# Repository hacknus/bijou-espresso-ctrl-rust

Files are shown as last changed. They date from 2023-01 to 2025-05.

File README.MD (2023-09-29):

### Bijou Espresso Machine Control Software (Rust Code)

This board controls the Bijou Espresso Machine.  
It is based around an STM32F405 microcontroller that reads out 5 PT100 RTDs (2 wire) using 5 MAX31865 ADCs.  
The temperature values are printed out over USB (CDC virtual COM Port) and shown on the SSD1306 OLED display.  
Two heating elements are controlled (SSR40 solid state relays) with PWM signals.  
Additionally a Buzzer and multiple LEDs can be controlled (PWM).  

The software uses freertos-rust (wrapper for rust) and thus requires nightly to compile.  
The embedded-graphics crate is used for the display.

Connect the board using a ST-Link V3 (with TagConnect) to a USB port on the computer. Be sure to power the board with an additional USB-C connector. (ST-Link does not provide power)  
First start the openocd server in a terminal/console window:
```openocd -f interface/stlink-v2-1.cfg -f target/stm32f4x.cfg```   
Flash/Run the code on the hardware using:  
```cargo run --package bijou-espresso-ctrl-rust --bin bijou-espresso-ctrl-rust --target thumbv7em-none-eabihf --release```  

To set up your system, be sure to follow [this guide](https://docs.rust-embedded.org/discovery/f3discovery/03-setup/index.html)!  
Don't forget to install the [ARM GNU toolchain](https://developer.arm.com/downloads/-/arm-gnu-toolchain-downloads).  
Make sure you add did 
```rustup install nightly``` and
```rustup target add thumbv7em-none-eabihf --toolchain nightly``` to add the target to the nightly toolchain.  

TODO:
- implement SPI flash chip in software

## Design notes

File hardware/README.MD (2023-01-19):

## Electronics Hardware of Bijou Espresso Machine 

The main board schematic can be found in `main.sch` and the pcb layout in `main.brd`.  
The AC power measurement board schematic can be found in `AC_board.sch` and the pcb layout in `AC_board.brd`. This is currently not implemented (in software).  
The temperature readout board schematic can be found in `temperature_2.sch` and the pcb layout in `temperature_2.brd`.  
Issues:
- footprint of the mosfets for the LED (Switch) is faulty, needs to be fixed.
- capacitor missing on encoder
- temperature molex connector is the wrong way around (needs to be soldered from the back)
- attention! usb serial resistors are 22 Ohms, not 220 Ohms!!

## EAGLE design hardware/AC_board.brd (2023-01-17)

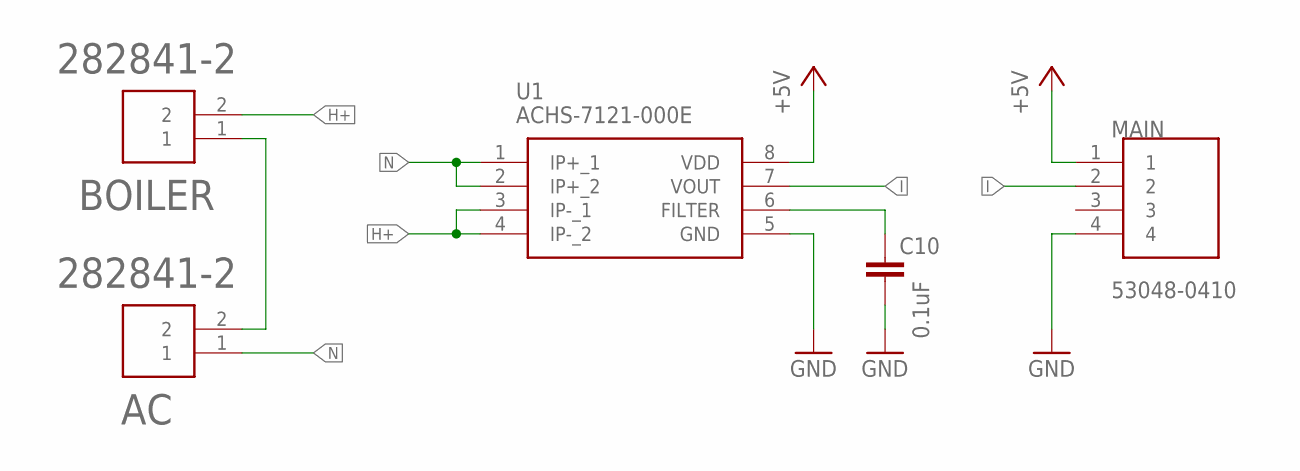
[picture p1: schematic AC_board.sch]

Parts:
AC: 282841-2; TE_282841-2
BOILER: 282841-2; TE_282841-2
C10: 0.1uF; C0603K
MAIN: 53048-0410; 530480410
U1: ACHS-7121-000E; SOIC127P606X204-8N

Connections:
+5V: MAIN.1, U1.8 (VDD)
GND: C10.2, MAIN.4, U1.5 (GND)
H+: BOILER.2, U1.3 (IP-_1), U1.4 (IP-_2)
I: MAIN.2, U1.7 (VOUT)
N: AC.1, U1.1 (IP+_1), U1.2 (IP+_2)
unnamed: C10.1, U1.6 (FILTER)
unnamed: AC.2, BOILER.1

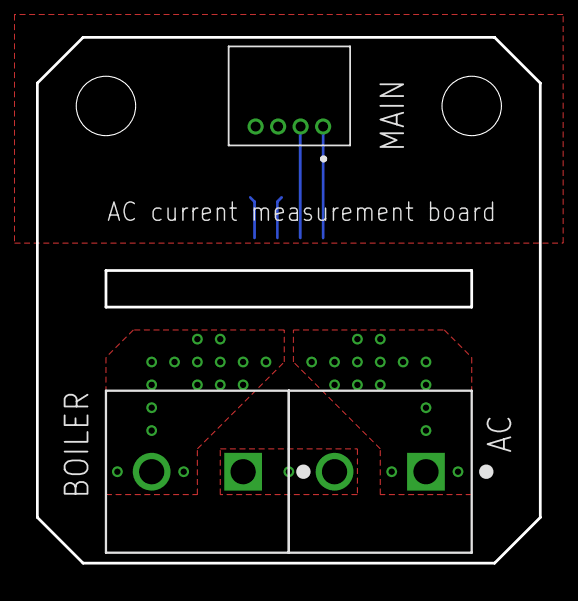
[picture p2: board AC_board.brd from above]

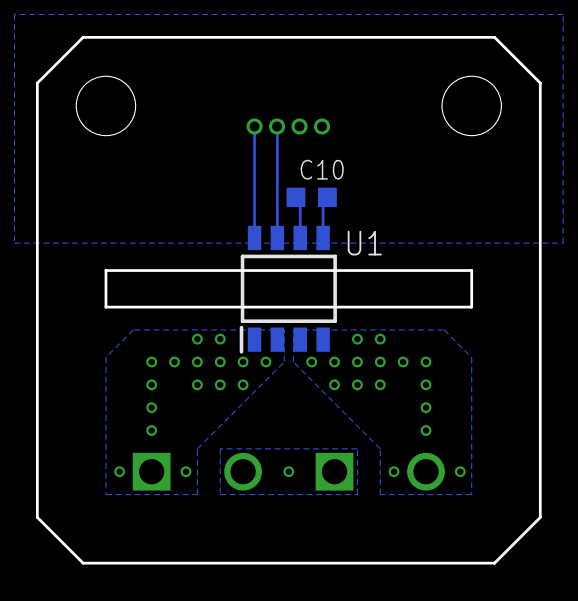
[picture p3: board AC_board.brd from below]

Board: 2 copper layers, 27.9 x 29.2 mm, 5 parts (2 on the bottom side), 7 nets.

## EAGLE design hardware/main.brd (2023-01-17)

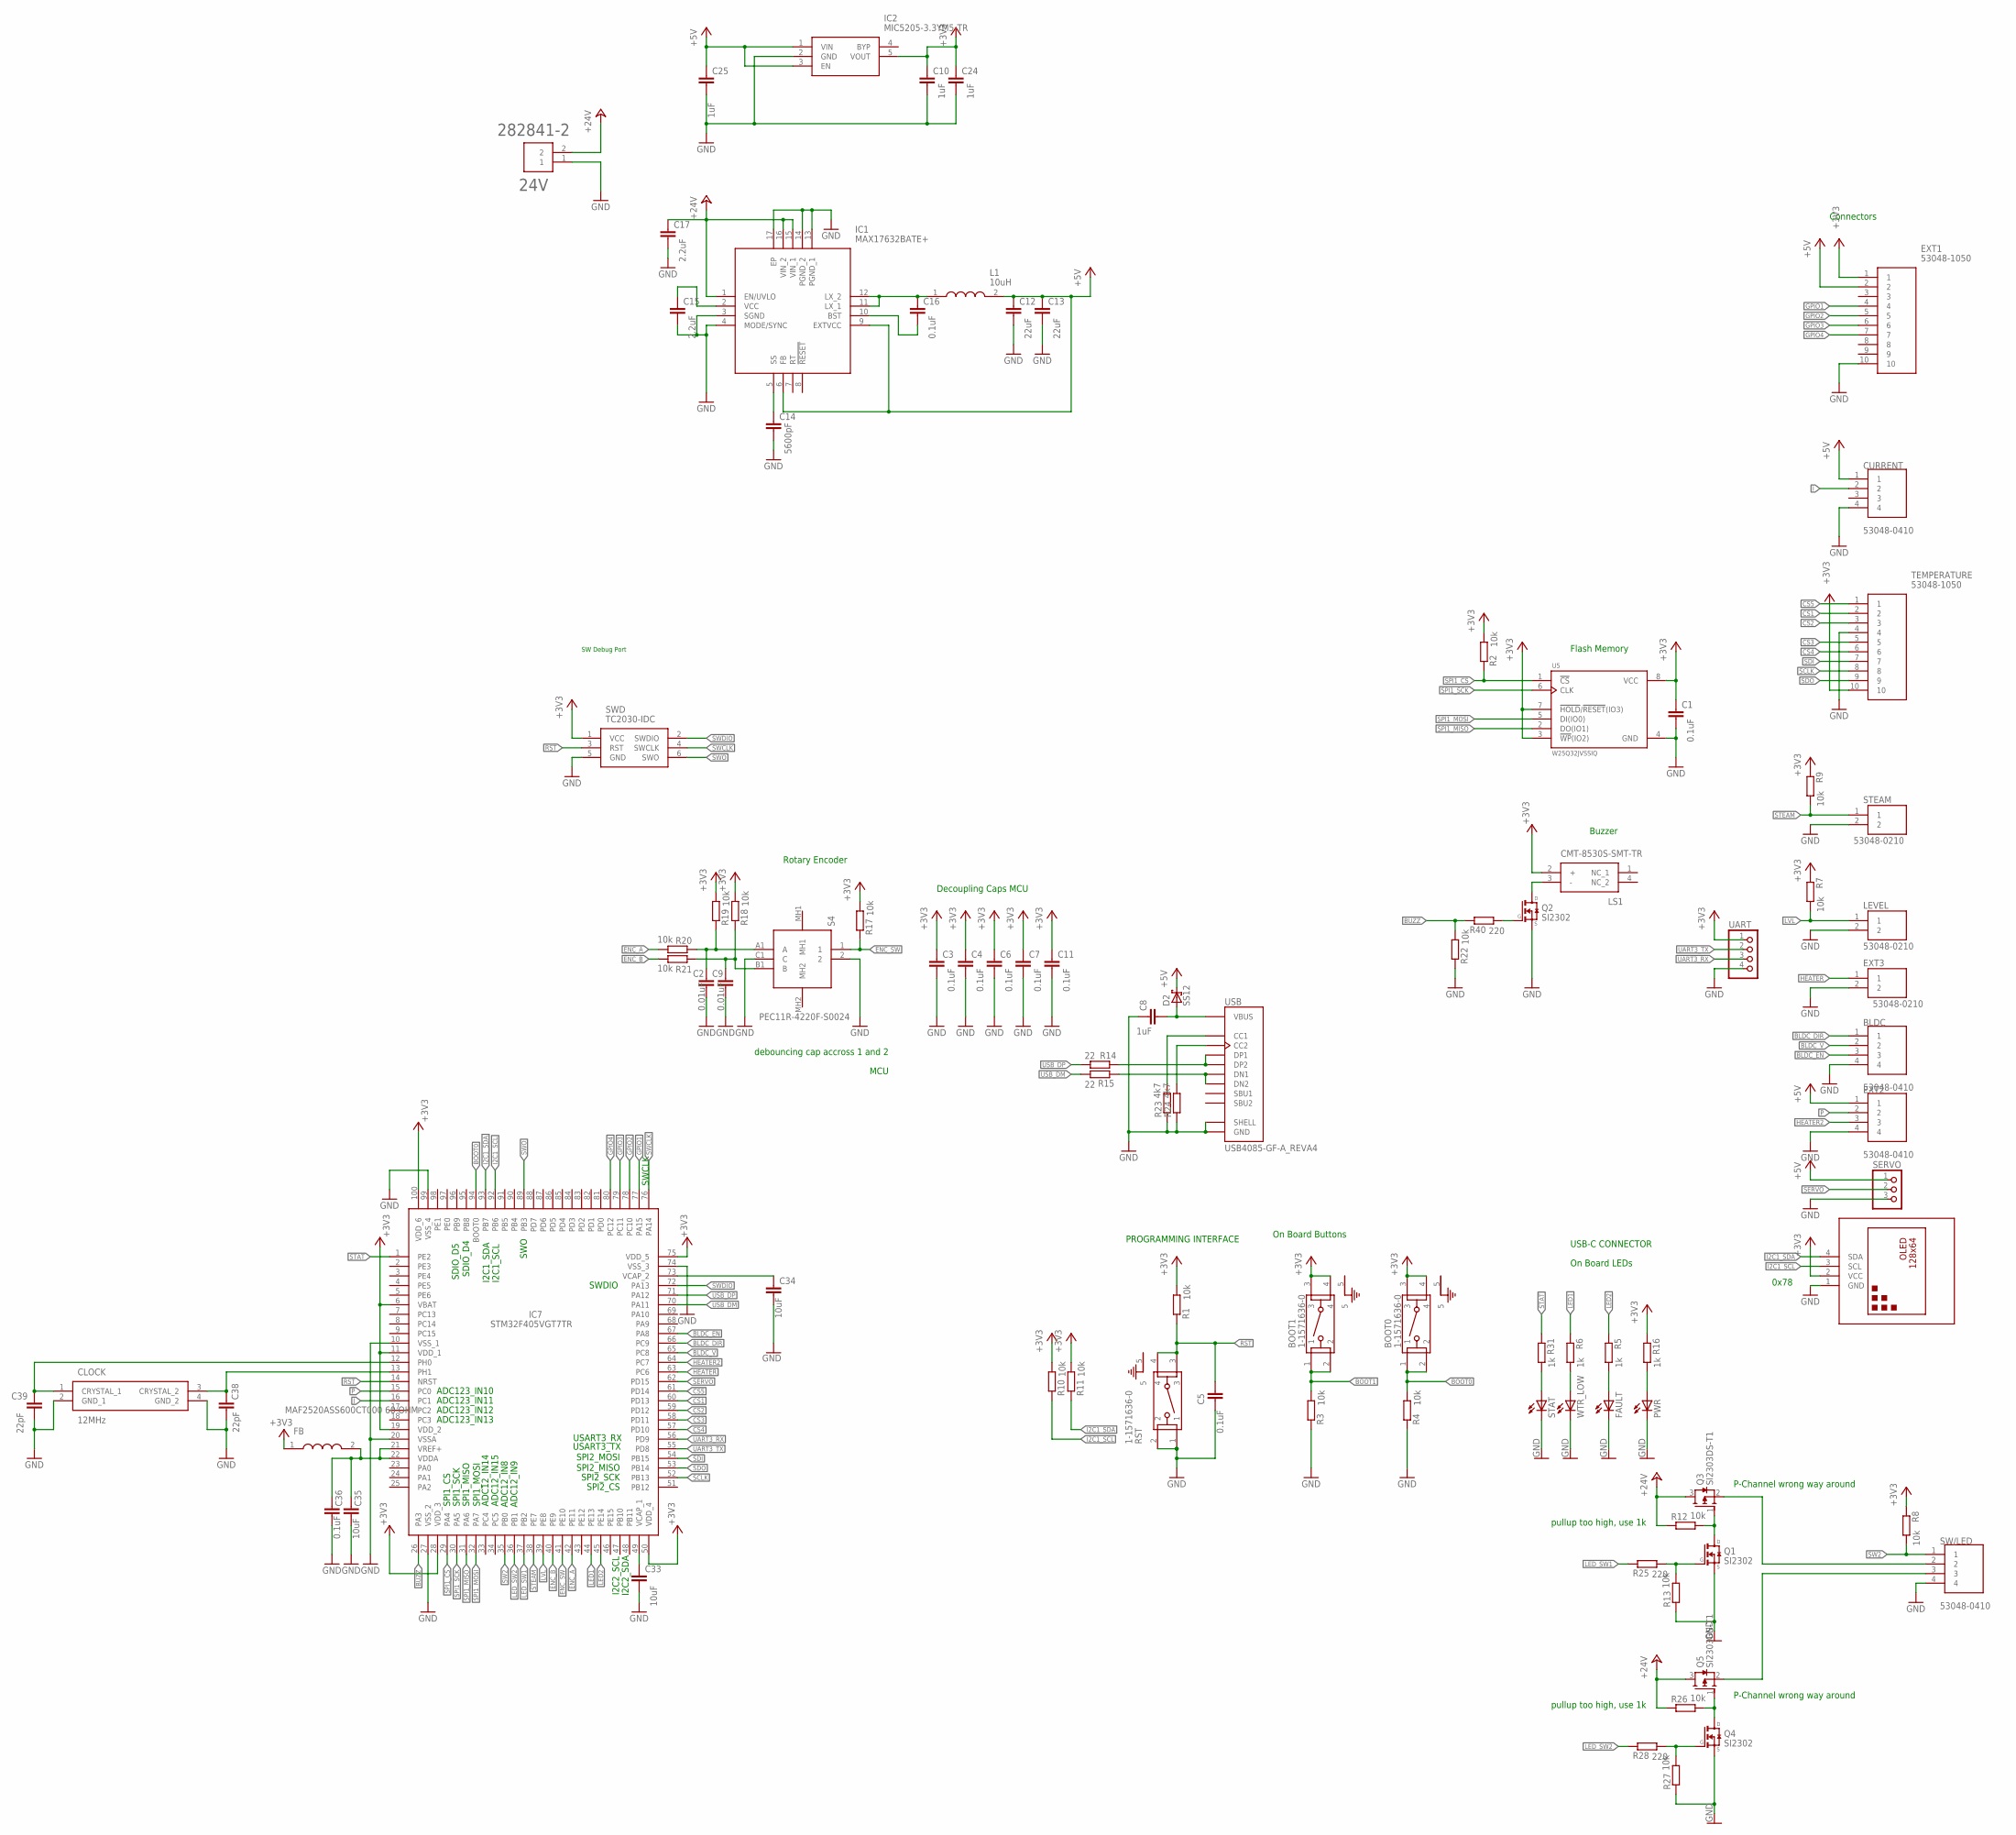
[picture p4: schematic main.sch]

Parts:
24V: 282841-2; TE_282841-2
BLDC: 53048-0410; 530480410
BOOT0, BOOT1: 1-1571636-0; SW5_1571636
C1, C3, C4, C5, C6, C7, C11, C16, C36: 0.1uF; C0603K
C2, C9: 0.01uF; C0603K
C8, C10, C24, C25: 1uF; C0603K
C12, C13: 22uF; C0603K
C14: 5600pF; C0603K
C15, C17: 2.2uF; C0603K
C33, C34, C35: 10uF; C0603K
C38, C39: 22pF; C0603K
CLOCK: 12MHz; ABM8AIG8000MHZ1ZT
CURRENT: 53048-0410; 530480410
D2: SS12; DO214AC
DISPLAY: DISPLAY-OLED-128X64-I2C
EXT1: 53048-1050; SHDRRA10W25P0X125_1X10_1425X55
EXT2: 53048-0410; 530480410
EXT3: 53048-0210; SHDRRA2W35P0X125_1X2_425X550X3
FAULT: LEDCHIPLED_0805; CHIPLED_0805
FB: MAF2520ASS600CT000 60 OHM; INDC2520X120N
IC1: MAX17632BATE+; QFN50P300X300X80-17N
IC2: MIC5205-3.3YM5-TR; SOT95P280X145-5N
IC7: STM32F405VGT7TR; QFP50P1600X1600X160-100N
L1: 10uH; INDC3225X270N
LEVEL: 53048-0210; SHDRRA2W35P0X125_1X2_425X550X3
LS1: CMT-8530S-SMT-TR; CMT8530SSMTTR
PWR: LEDCHIPLED_0805; CHIPLED_0805
Q1, Q2, Q4: SI2302; SOT23
Q3, Q5: SI2303DS-T1; SOT90P248X115-3N
R1, R2, R3, R4, R7, R8, R9, R10, R11, R12, R13, R17, R18, R19, R20, R21, R22, R26, R27: 10k; R0603
R5, R6, R16, R31: 1k; R0603
R14, R15: 22; R0603
R23, R24: 4k7; R0603
R25, R28, R40: 220; R0603
RST: 1-1571636-0; SW5_1571636
S4: PEC11R-4220F-S0024; PEC11R4220FS0024
SERVO: PINHD-1X3/90; 1X03/90
STAT: LEDCHIPLED_0805; CHIPLED_0805
STEAM: 53048-0210; SHDRRA2W35P0X125_1X2_425X550X3
SW/LED: 53048-0410; 530480410
SWD: TC2030-IDC; TC2030IDC
TEMPERATURE: 53048-1050; SHDRRA10W25P0X125_1X10_1425X55
U5: W25Q32JVSSIQ; SOIC127P790X216-8N
UART: PINHD-1X4; 1X04
USB: USB4085-GF-A_REVA4; GCT_USB4085-GF-A_REVA4
WTR_LOW: LEDCHIPLED_0805; CHIPLED_0805

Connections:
+3V3: BOOT0.3, BOOT0.4, BOOT1.3, BOOT1.4, C1.1, C3.1, C4.1, C6.1, C7.1, C10.1, C11.1, C24.1, DISPLAY.2 (VCC), EXT1.1, FB.1, IC2.5 (VOUT), IC7.6 (VBAT), IC7.11 (VDD_1), IC7.19 (VDD_2), IC7.28 (VDD_3), IC7.50 (VDD_4), IC7.75 (VDD_5), IC7.100 (VDD_6), LS1.2 (+), R1.2, R2.2, R7.1, R8.1, R9.1, R10.2, R11.2, R16.1, R17.2, R18.2, R19.2, SWD.1 (VCC), TEMPERATURE.10, U5.3 (!WP!(IO2)), U5.7 (!HOLD!/!RESET!(IO3)), U5.8 (VCC), UART.1
+5V: C12.1, C13.1, C25.1, CURRENT.1, D2.C, EXT1.2, EXT2.1, IC1.6 (FB), IC1.9 (EXTVCC), IC2.1 (VIN), IC2.3 (EN), L1.2, SERVO.1
+24V: 24V.2, C17.1, IC1.1 (EN/UVLO), IC1.15 (VIN_1), IC1.16 (VIN_2), Q3.3 (D), Q5.3 (D), R12.1, R26.1
BLDC_DIR: BLDC.1, IC7.66 (PC9)
BLDC_EN: BLDC.3, IC7.67 (PA8)
BLDC_V: BLDC.2, IC7.65 (PC8)
BOOT0: BOOT0.1, BOOT0.2, IC7.94 (BOOT0), R4.2
BOOT1: BOOT1.1, BOOT1.2, R3.2
BUZZ: IC7.26 (PA3), R22.2, R40.1
CS1: IC7.60 (PD13), TEMPERATURE.2
CS2: IC7.59 (PD12), TEMPERATURE.3
CS3: IC7.58 (PD11), TEMPERATURE.5
CS4: IC7.57 (PD10), TEMPERATURE.6
CS5: IC7.61 (PD14), TEMPERATURE.1
ENC_A: IC7.42 (PE11), R20.2
ENC_B: IC7.40 (PE9), R21.2
ENC_SW: IC7.41 (PE10), R17.1, S4.1
GND: 24V.1, BLDC.4, C1.2, C2.2, C3.2, C4.2, C5.2, C6.2, C7.2, C8.1, C9.2, C10.2, C11.2, C12.2, C13.2, C14.2, C15.2, C17.2, C24.2, C25.2, C33.2, C34.2, C35.2, C36.2, C38.2, C39.2, CLOCK.2 (GND_1), CLOCK.4 (GND_2), CURRENT.4, DISPLAY.1 (GND), EXT1.10, EXT2.4, EXT3.2, FAULT.C, IC1.3 (SGND), IC1.4 (MODE/SYNC), IC1.13 (PGND_1), IC1.14 (PGND_2), IC1.17 (EP), IC2.2 (GND), IC7.10 (VSS_1), IC7.20 (VSSA), IC7.27 (VSS_2), IC7.74 (VSS_3), IC7.99 (VSS_4), LEVEL.2, PWR.C, Q1.2 (S), Q2.2 (S), Q4.2 (S), R3.1, R4.1, R13.1, R22.1, R23.1, R24.1, R27.1, RST.1, RST.2, S4.2, S4.C1 (C), SERVO.3, STAT.C, STEAM.2, SW/LED.4, SWD.5 (GND), TEMPERATURE.4, U5.4 (GND), UART.4, USB.A1 (GND), USB.A12 (GND), USB.B1 (GND), USB.B12 (GND), USB.P1 (SHELL), USB.P2 (SHELL), USB.P3 (SHELL), USB.P4 (SHELL), WTR_LOW.C
GPIO1: EXT1.4, IC7.77 (PA15)
GPIO2: EXT1.5, IC7.78 (PC10)
GPIO3: EXT1.6, IC7.79 (PC11)
GPIO4: EXT1.7, IC7.80 (PC12)
HEATER: EXT3.1, IC7.63 (PC6)
HEATER2: EXT2.3, IC7.64 (PC7)
I: CURRENT.2, IC7.16 (PC1)
I2C1_SCL: DISPLAY.3 (SCL), IC7.92 (PB6), R10.1
I2C1_SDA: DISPLAY.4 (SDA), IC7.93 (PB7), R11.1
LED1: IC7.44 (PE13), R6.1
LED2: IC7.45 (PE14), R5.1
LED_SW1: IC7.37 (PB2), R25.1
LED_SW2: IC7.36 (PB1), R28.1
LVL: IC7.39 (PE8), LEVEL.1, R7.2
unnamed: R14.1, USB.A6 (DP1), USB.B6 (DP2)
unnamed: R15.1, USB.A7 (DN1), USB.B7 (DN2)
unnamed: R24.2, USB.B5 (CC2)
unnamed: R23.2, USB.A5 (CC1)
unnamed: LS1.3 (-), Q2.3 (D)
unnamed: R6.2, WTR_LOW.A
unnamed: PWR.A, R16.2
unnamed: FAULT.A, R5.2
unnamed: R31.2, STAT.A
unnamed: C9.1, R18.1, R21.1, S4.B1 (B)
unnamed: C14.1, IC1.5 (SS)
unnamed: C2.1, R19.1, R20.1, S4.A1 (A)
unnamed: C16.2, IC1.10 (BST)
unnamed: C8.2, D2.A, USB.A4 (VBUS), USB.A9 (VBUS), USB.B4 (VBUS), USB.B9 (VBUS)
unnamed: Q1.3 (D), Q3.1 (G), R12.2
unnamed: C15.1, IC1.2 (VCC)
unnamed: C16.1, IC1.11 (LX_1), IC1.12 (LX_2), L1.1
unnamed: Q1.1 (G), R13.2, R25.2
unnamed: C34.1, IC7.73 (VCAP_2)
unnamed: Q4.3 (D), Q5.1 (G), R26.2
unnamed: Q4.1 (G), R27.2, R28.2
unnamed: C35.1, C36.1, FB.2, IC7.21 (VREF+), IC7.22 (VDDA)
unnamed: Q3.2 (S), SW/LED.2
unnamed: Q5.2 (S), SW/LED.3
unnamed: Q2.1 (G), R40.2
unnamed: C33.1, IC7.49 (VCAP_1)
unnamed: C38.1, CLOCK.3 (CRYSTAL_2), IC7.13 (PH1)
unnamed: C39.1, CLOCK.1 (CRYSTAL_1), IC7.12 (PH0)
P: EXT2.2, IC7.15 (PC0)
RST: C5.1, IC7.14 (NRST), R1.1, RST.3, RST.4, SWD.3 (RST)
SCLK: IC7.52 (PB13), TEMPERATURE.8
SDI: IC7.54 (PB15), TEMPERATURE.7
SDO: IC7.53 (PB14), TEMPERATURE.9
SERVO: IC7.62 (PD15), SERVO.2
SPI1_CS: IC7.29 (PA4), R2.1, U5.1 (!CS)
SPI1_MISO: IC7.31 (PA6), U5.2 (DO(IO1))
SPI1_MOSI: IC7.32 (PA7), U5.5 (DI(IO0))
SPI1_SCK: IC7.30 (PA5), U5.6 (CLK)
STAT: IC7.1 (PE2), R31.1
STEAM: IC7.38 (PE7), R9.2, STEAM.1
SW2: IC7.35 (PB0), R8.2, SW/LED.1
SWCLK: IC7.76 (PA14), SWD.4 (SWCLK)
SWDIO: IC7.72 (PA13), SWD.2 (SWDIO)
SWO: IC7.89 (PB3), SWD.6 (SWO)
UART3_RX: IC7.56 (PD9), UART.3
UART3_TX: IC7.55 (PD8), UART.2
USB_DM: IC7.70 (PA11), R15.2
USB_DP: IC7.71 (PA12), R14.2

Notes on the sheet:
I2C1_SDA
I2C1_SCL
I2C2_SCL
I2C2_SDA
SPI1_CS
SPI1_SCK
SPI1_MISO
SPI1_MOSI
SPI2_CS
SPI2_SCK
SPI2_MISO
SPI2_MOSI
SWDIO
SWCLK
SWO
SDIO_D4
SDIO_D5
ADC123_IN10
ADC123_IN11
ADC123_IN12
ADC123_IN13
ADC12_IN14
ADC12_IN15
ADC12_IN8
ADC12_IN9
USART3_TX
USART3_RX
SW Debug Port
Buzzer
Flash Memory
On Board Buttons
On Board LEDs
Connectors
Decoupling Caps MCU
MCU
Rotary Encoder
USB-C CONNECTOR
PROGRAMMING INTERFACE
0x78
debouncing cap accross 1 and 2

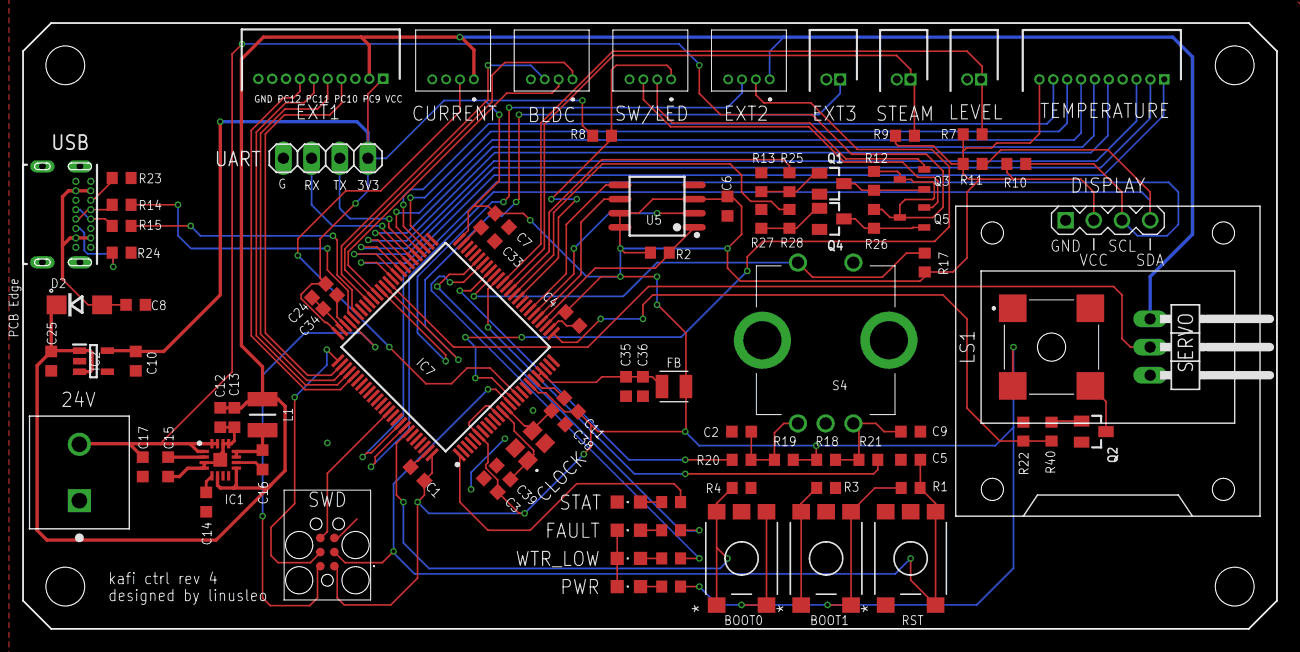
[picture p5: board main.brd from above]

Board: 2 copper layers, 113.0 x 54.6 mm, 92 parts (0 on the bottom side), 80 nets.

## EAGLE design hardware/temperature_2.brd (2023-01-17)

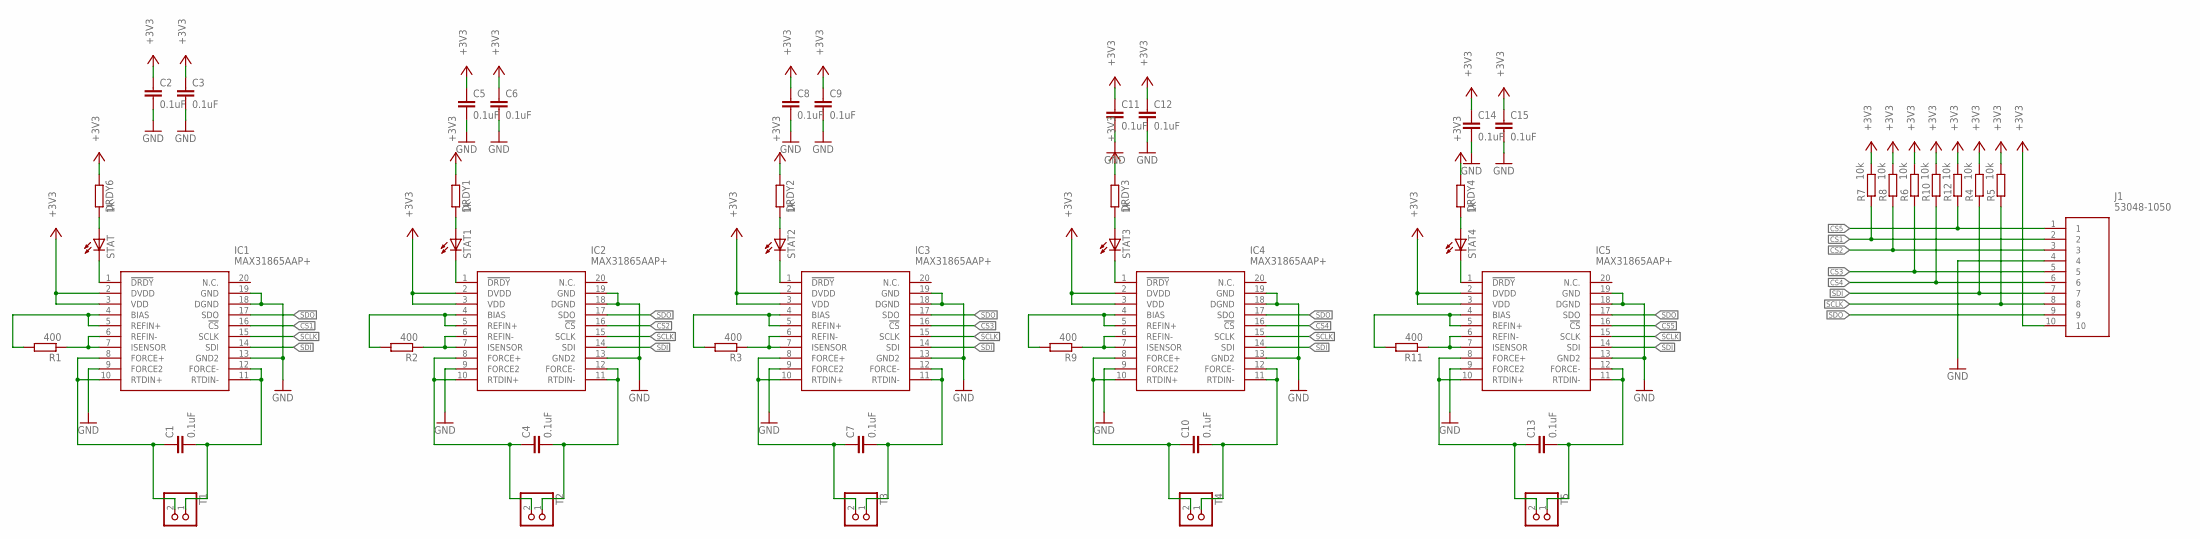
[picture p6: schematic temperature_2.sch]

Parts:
C1, C2, C3, C4, C5, C6, C7, C8, C9, C10, C11, C12, C13, C14, C15: 0.1uF; C0603K
DRDY1, DRDY2, DRDY3, DRDY4, DRDY6: 1k; R0603
IC1, IC2, IC3, IC4, IC5: MAX31865AAP+; SOP65P778X199-20N
J1: 53048-1050; SHDRRA10W25P0X125_1X10_1425X55
R1, R2, R3, R9, R11: 400; R1206
R4, R5, R6, R7, R8, R10, R12: 10k; R0603
STAT, STAT1, STAT2, STAT3, STAT4: LEDCHIPLED_0805; CHIPLED_0805
T1, T2, T3, T4, T5: PINHD-1X2; 1X02

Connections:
+3V3: C2.1, C3.1, C5.1, C6.1, C8.1, C9.1, C11.1, C12.1, C14.1, C15.1, DRDY1.1, DRDY2.1, DRDY3.1, DRDY4.1, DRDY6.1, IC1.2 (DVDD), IC1.3 (VDD), IC2.2 (DVDD), IC2.3 (VDD), IC3.2 (DVDD), IC3.3 (VDD), IC4.2 (DVDD), IC4.3 (VDD), IC5.2 (DVDD), IC5.3 (VDD), J1.10, R4.2, R5.2, R6.2, R7.2, R8.2, R10.2, R12.2
CS1: IC1.16 (!CS), J1.2, R7.1
CS2: IC2.16 (!CS), J1.3, R8.1
CS3: IC3.16 (!CS), J1.5, R6.1
CS4: IC4.16 (!CS), J1.6, R10.1
CS5: IC5.16 (!CS), J1.1, R12.1
GND: C2.2, C3.2, C5.2, C6.2, C8.2, C9.2, C11.2, C12.2, C14.2, C15.2, IC1.9 (FORCE2), IC1.13 (GND2), IC1.18 (DGND), IC1.19 (GND), IC2.9 (FORCE2), IC2.13 (GND2), IC2.18 (DGND), IC2.19 (GND), IC3.9 (FORCE2), IC3.13 (GND2), IC3.18 (DGND), IC3.19 (GND), IC4.9 (FORCE2), IC4.13 (GND2), IC4.18 (DGND), IC4.19 (GND), IC5.9 (FORCE2), IC5.13 (GND2), IC5.18 (DGND), IC5.19 (GND), J1.4
unnamed: IC2.4 (BIAS), IC2.5 (REFIN+), R2.2
unnamed: IC2.6 (REFIN-), IC2.7 (ISENSOR), R2.1
unnamed: C4.1, IC2.8 (FORCE+), IC2.10 (RTDIN+), T2.2
unnamed: C4.2, IC2.11 (RTDIN-), IC2.12 (FORCE-), T2.1
unnamed: IC3.4 (BIAS), IC3.5 (REFIN+), R3.2
unnamed: IC3.6 (REFIN-), IC3.7 (ISENSOR), R3.1
unnamed: C7.1, IC3.8 (FORCE+), IC3.10 (RTDIN+), T3.2
unnamed: C7.2, IC3.11 (RTDIN-), IC3.12 (FORCE-), T3.1
unnamed: IC4.4 (BIAS), IC4.5 (REFIN+), R9.2
unnamed: IC4.6 (REFIN-), IC4.7 (ISENSOR), R9.1
unnamed: C10.1, IC4.8 (FORCE+), IC4.10 (RTDIN+), T4.2
unnamed: C10.2, IC4.11 (RTDIN-), IC4.12 (FORCE-), T4.1
unnamed: IC5.4 (BIAS), IC5.5 (REFIN+), R11.2
unnamed: IC5.6 (REFIN-), IC5.7 (ISENSOR), R11.1
unnamed: C13.1, IC5.8 (FORCE+), IC5.10 (RTDIN+), T5.2
unnamed: C13.2, IC5.11 (RTDIN-), IC5.12 (FORCE-), T5.1
unnamed: DRDY6.2, STAT.A
unnamed: IC1.1 (!DRDY), STAT.C
unnamed: DRDY1.2, STAT1.A
unnamed: IC2.1 (!DRDY), STAT1.C
unnamed: DRDY2.2, STAT2.A
unnamed: IC1.4 (BIAS), IC1.5 (REFIN+), R1.2
unnamed: IC1.6 (REFIN-), IC1.7 (ISENSOR), R1.1
unnamed: IC3.1 (!DRDY), STAT2.C
unnamed: C1.1, IC1.8 (FORCE+), IC1.10 (RTDIN+), T1.2
unnamed: C1.2, IC1.11 (RTDIN-), IC1.12 (FORCE-), T1.1
unnamed: DRDY3.2, STAT3.A
unnamed: IC4.1 (!DRDY), STAT3.C
unnamed: DRDY4.2, STAT4.A
unnamed: IC5.1 (!DRDY), STAT4.C
SCLK: IC1.15 (SCLK), IC2.15 (SCLK), IC3.15 (SCLK), IC4.15 (SCLK), IC5.15 (SCLK), J1.8, R5.1
SDI: IC1.14 (SDI), IC2.14 (SDI), IC3.14 (SDI), IC4.14 (SDI), IC5.14 (SDI), J1.7, R4.1
SDO: IC1.17 (SDO), IC2.17 (SDO), IC3.17 (SDO), IC4.17 (SDO), IC5.17 (SDO), J1.9

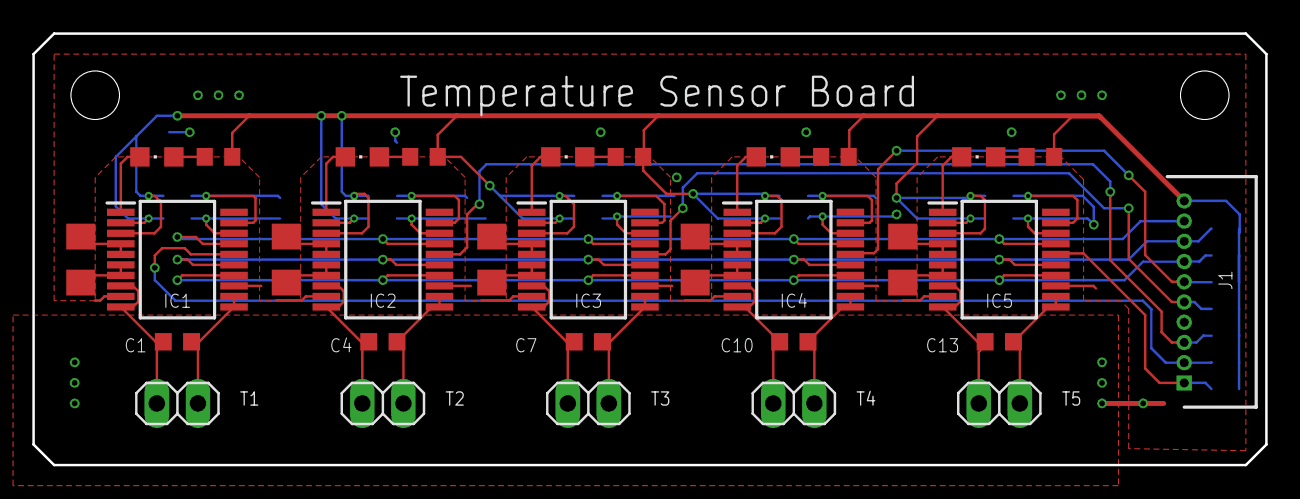
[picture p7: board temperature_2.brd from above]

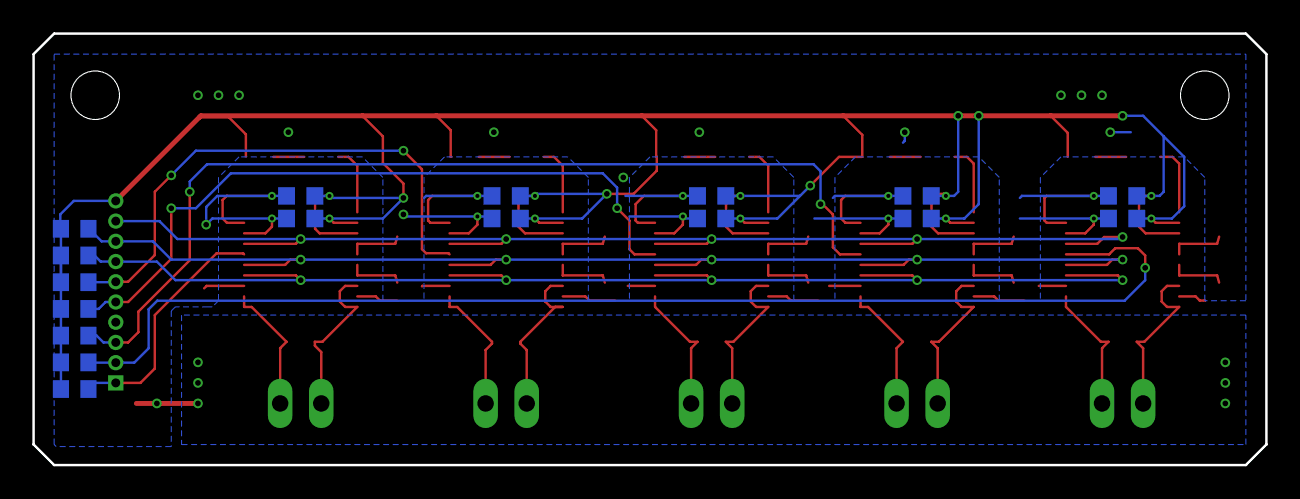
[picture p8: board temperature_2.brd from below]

Board: 2 copper layers, 76.2 x 26.7 mm, 48 parts (17 on the bottom side), 40 nets.

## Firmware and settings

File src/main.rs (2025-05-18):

//#![deny(unsafe_code)]
#![no_main]
#![no_std]
// For allocator
#![feature(lang_items)]
#![feature(alloc_error_handler)]

extern crate alloc;

use alloc::sync::Arc;
use core::f32::consts::PI;
use core::panic::PanicInfo;

use arrform::{arrform, ArrForm};
use cortex_m::asm;
use cortex_m_rt::exception;
use cortex_m_rt::{entry, ExceptionFrame};
use embedded_graphics::{
    image::Image,
    mono_font::{ascii::FONT_6X10, MonoTextStyle},
    pixelcolor::BinaryColor,
    pixelcolor::Rgb565,
    prelude::*,
    text::Text,
};
use freertos_rust::*;
use micromath::F32Ext;
use ssd1306::{prelude::*, I2CDisplayInterface, Ssd1306};
use stm32f4xx_hal::adc::config::{AdcConfig, Dma, SampleTime, Scan, Sequence};
use stm32f4xx_hal::adc::{Adc, Temperature};
use stm32f4xx_hal::dma::config::DmaConfig;
use stm32f4xx_hal::dma::{StreamsTuple, Transfer};
use stm32f4xx_hal::timer::{Channel1, Channel2};
use stm32f4xx_hal::{
    gpio::Edge,
    i2c::Mode as i2cMode,
    otg_fs::USB,
    pac::Peripherals,
    pac::{self, Interrupt},
    prelude::*,
    spi::{Mode as spiMode, Phase, Polarity},
    timer::{Channel, Channel3, Channel4},
};
use tinybmp::Bmp;

use crate::commands::{
    extract_command, send_housekeeping, HeaterCommand, PumpCommand, ValveCommand,
};
use crate::devices::led::LED;
use crate::devices::max31865::Wires;
use crate::devices::max31865::MAX31865;
use crate::devices::pressure_sense::{read_pressure, ADC_MEMORY, G_XFR};
use crate::intrpt::{G_ENC_PIN_A, G_ENC_PIN_B, G_ENC_STATE};
use crate::mav::Mav;
use crate::pid::{PID, STEADY_STATE_BOUNDS};
use crate::usb::{usb_init, usb_println, usb_read};
use crate::utils::{
    CoffeeState, HeaterState, Interface, LedState, MeasuredData, PidData, PumpData, PumpState,
    State, ValveState,
};

mod commands;
mod devices;
mod intrpt;
mod mav;
mod pid;
mod usb;
mod utils;

static mut SHUTDOWN: bool = false;

#[global_allocator]
static GLOBAL: FreeRtosAllocator = FreeRtosAllocator;

fn check_shutdown() -> bool {
    cortex_m::interrupt::free(|_| unsafe { SHUTDOWN })
}

#[entry]
fn main() -> ! {
    let mut dp = pac::Peripherals::take().unwrap();

    let rcc = dp.RCC.constrain();

    let clocks = rcc
        .cfgr
        .use_hse(8.MHz())
        .sysclk(48.MHz())
        .hclk(48.MHz())
        .require_pll48clk()
        .pclk1(24.MHz())
        .pclk2(24.MHz())
        .freeze();

    // initialize ports
    let gpioa = dp.GPIOA.split();
    let gpiob = dp.GPIOB.split();
    let gpioc = dp.GPIOC.split();
    let gpiod = dp.GPIOD.split();
    let gpioe = dp.GPIOE.split();

    // initialize leds
    let mut stat_led = LED::new(gpioe.pe2.into_push_pull_output());
    let mut fault_1_led = LED::new(gpioe.pe13.into_push_pull_output());
    let mut fault_2_led = LED::new(gpioe.pe14.into_push_pull_output());

    // TODO check if TIM4 actually works, before it was TIM5
    let mut tick_timer = dp.TIM4.counter_ms(&clocks);
    // tick_timer.start(2_678_400_000.millis()).unwrap(); // set the timeout to 31 days

    stat_led.on();

    let mut delay = dp.TIM1.delay_us(&clocks);
    delay.delay(100.millis()); // apparently required for USB to set up properly...

    // initialize DMA
    let dma2 = StreamsTuple::new(dp.DMA2);

    // initialize pins
    let cs_5 = gpiod.pd14.into_push_pull_output();
    let cs_4 = gpiod.pd10.into_push_pull_output();
    let cs_3 = gpiod.pd11.into_push_pull_output();
    let cs_2 = gpiod.pd12.into_push_pull_output();
    let cs_1 = gpiod.pd13.into_push_pull_output();
    let mut bldc_en = gpioa.pa8.into_push_pull_output();
    let mut bldc_dir = gpioc.pc9.into_push_pull_output();
    bldc_dir.set_low();
    let water_low = false; // TODO: implement water_low pin
    let heater_1 = Channel1::new(gpioc.pc6);
    let heater_2 = Channel2::new(gpioc.pc7);
    let heater_bg = Channel3::new(gpioa.pa2);

    let lever = gpioe.pe7.into_floating_input();
    let bldc_v = Channel3::new(gpioc.pc8);
    let buzz = Channel4::new(gpioa.pa3);
    let led_dim = Channel4::new(gpiob.pb1);

    let enc_pin_a = gpioe.pe11.into_floating_input();
    let mut enc_pin_b = gpioe.pe9.into_floating_input();
    let _enc_pin_sw = gpioe.pe10.into_floating_input();
    let mut syscfg = dp.SYSCFG.constrain();
    enc_pin_b.make_interrupt_source(&mut syscfg);
    enc_pin_b.trigger_on_edge(&mut dp.EXTI, Edge::RisingFalling);
    enc_pin_b.enable_interrupt(&mut dp.EXTI);

    // initialize button
    let button = gpiob.pb0.into_floating_input();

    // initialize extension pins
    let _pin_a_15 = gpioa.pa15.into_push_pull_output();
    let mut valve1_pin = gpioc.pc10.into_push_pull_output();
    let mut valve2_pin = gpioc.pc11.into_push_pull_output();
    let _pin_c_12 = gpioc.pc12.into_push_pull_output();

    valve1_pin.set_high();
    valve2_pin.set_high();

    // initialize buzzer
    let mut buzz_pwm = dp.TIM2.pwm_hz(buzz, 2000.Hz(), &clocks);
    let max_duty = buzz_pwm.get_max_duty();
    buzz_pwm.set_duty(Channel::C4, max_duty / 2);

    // initialize pwm timer 3
    let (mut bldc_pwm, mut led_pwm) = dp
        .TIM3
        .pwm_hz((bldc_v, led_dim), 10000.Hz(), &clocks)
        .split();

    // initialize dimming LED
    let max_duty = led_pwm.get_max_duty();
    led_pwm.set_duty(max_duty / 2);

    // initialize bldc pwm
    let max_duty = bldc_pwm.get_max_duty();
    bldc_pwm.set_duty(max_duty / 2);

    // initialize heater 1 pwm

    // initialize heater 2 pwm
    let (mut heater_1_pwm, mut heater_2_pwm) = dp
        .TIM8
        .pwm_hz((heater_1, heater_2), 3.Hz(), &clocks)
        .split();
    heater_1_pwm.set_duty(0);
    heater_2_pwm.set_duty(0);

    // initialize heater bg pwm
    let mut heater_bg_pwm = dp.TIM5.pwm_hz(heater_bg, 3.Hz(), &clocks);
    heater_bg_pwm.set_duty(Channel::C3, 0);

    // initialize usb
    let usb = USB {
        usb_global: dp.OTG_FS_GLOBAL,
        usb_device: dp.OTG_FS_DEVICE,
        usb_pwrclk: dp.OTG_FS_PWRCLK,
        pin_dm: stm32f4xx_hal::gpio::alt::otg_fs::Dm::PA11(gpioa.pa11.into_alternate()),
        pin_dp: stm32f4xx_hal::gpio::alt::otg_fs::Dp::PA12(gpioa.pa12.into_alternate()),
        hclk: clocks.hclk(),
    };

    delay.delay(100.millis());
    unsafe {
        usb_init(usb);
        cortex_m::peripheral::NVIC::unmask(Interrupt::OTG_FS);
        cortex_m::peripheral::NVIC::unmask(Interrupt::DMA2_STREAM0);
        cortex_m::peripheral::NVIC::unmask(enc_pin_b.interrupt());
    }
    // Now that button is configured, move button into global context
    cortex_m::interrupt::free(|cs| {
        G_ENC_PIN_A.borrow(cs).replace(Some(enc_pin_a));
    });
    // Now that button is configured, move button into global context
    cortex_m::interrupt::free(|cs| {
        G_ENC_PIN_B.borrow(cs).replace(Some(enc_pin_b));
    });

    stat_led.on();
    // usb_println("usb set up ok");

    let mut pos: isize = 0;

    let scl = gpiob.pb6;
    let sda = gpiob.pb7;
    // initialize i2c
    let i2c = dp.I2C1.i2c(
        (scl, sda),
        i2cMode::Standard {
            frequency: 100.kHz(),
        },
        &clocks,
    );

    let interface = I2CDisplayInterface::new(i2c);
    let bmp =
        Bmp::from_slice(include_bytes!("../images/rust.bmp")).expect("Failed to load BMP image");
    // let bmp_inv = Bmp::from_slice(include_bytes!("../images/rust1.bmp")).expect("Failed to load BMP image");

    let mut display = Ssd1306::new(interface, DisplaySize128x64, DisplayRotation::Rotate0)
        .into_buffered_graphics_mode();
    display.init().unwrap();

    let sclk = gpiob.pb13;
    let sdo = gpiob.pb14;
    let sdi = gpiob.pb15;

    // initialize spi
    let spi = dp.SPI2.spi(
        (sclk, sdo, sdi),
        spiMode {
            polarity: Polarity::IdleHigh,
            phase: Phase::CaptureOnSecondTransition,
        },
        10.kHz(),
        &clocks,
    );

    let spi_bus = shared_bus::BusManagerSimple::new(spi);

    // init adc
    let pressure_sense_pin = gpioc.pc0.into_analog();
    let current_sense_pin = gpioc.pc1.into_analog();

    let dma_config = DmaConfig::default()
        .transfer_complete_interrupt(true)
        .memory_increment(true)
        .double_buffer(false);

    let adc_config = AdcConfig::default()
        .dma(Dma::Continuous)
        .scan(Scan::Enabled);

    let mut adc = Adc::adc1(dp.ADC1, true, adc_config);

    adc.configure_channel(&Temperature, Sequence::One, SampleTime::Cycles_480);
    adc.configure_channel(&pressure_sense_pin, Sequence::Two, SampleTime::Cycles_480);
    adc.configure_channel(&current_sense_pin, Sequence::Three, SampleTime::Cycles_480);
    adc.enable_temperature_and_vref();

    // let adc_buffer = cortex_m::singleton!(: [u16; 2] = [0; 2]).unwrap();
    let mut transfer = unsafe {
        Transfer::init_peripheral_to_memory(dma2.0, adc, &mut ADC_MEMORY, None, dma_config)
    };

    transfer.start(|adc| {
        adc.start_conversion();
    });
    cortex_m::interrupt::free(|cs| {
        G_XFR.borrow(cs).replace(Some(transfer));
    });

    let led_state = LedState::Off;
    let led_state_container =
        Arc::new(Mutex::new(led_state).expect("Failed to create data guard mutex"));
    let led_state_container_main = led_state_container.clone();
    let led_state_container_led = led_state_container;

    let state = State::default();
    let state_container = Arc::new(Mutex::new(state).expect("Failed to create data guard mutex"));
    let state_container_main = state_container.clone();
    let state_container_usb = state_container.clone();
    let state_container_pid = state_container;

    let measured_data = MeasuredData::default();
    let measured_data_container =
        Arc::new(Mutex::new(measured_data).expect("Failed to create data guard mutex"));
    let measured_data_container_display = measured_data_container.clone();
    let measured_data_container_adc = measured_data_container.clone();
    let measured_data_container_main = measured_data_container.clone();
    let measured_data_container_pid_1 = measured_data_container.clone();
    let measured_data_container_pid_2 = measured_data_container.clone();
    let measured_data_container_pid_bg = measured_data_container.clone();
    let measured_data_container_usb = measured_data_container;

    let pid_data_1 = PidData::default();
    let pid_data_1_container =
        Arc::new(Mutex::new(pid_data_1).expect("Failed to create data guard mutex"));
    let _pid_data_1_container_display = pid_data_1_container.clone();
    let pid_1_data_container_pid_1 = pid_data_1_container.clone();
    let pid_1_data_container_main = pid_data_1_container.clone();
    let pid_1_data_container_usb = pid_data_1_container;

    let pid_data_2 = PidData::default();
    let pid_data_2_container =
        Arc::new(Mutex::new(pid_data_2).expect("Failed to create data guard mutex"));
    let _pid_data_2_container_display = pid_data_2_container.clone();
    let pid_2_data_container_pid_2 = pid_data_2_container.clone();
    let pid_2_data_container_main = pid_data_2_container.clone();
    let pid_2_data_container_usb = pid_data_2_container;

    let pid_data_bg = PidData::default();
    let pid_data_bg_container =
        Arc::new(Mutex::new(pid_data_bg).expect("Failed to create data guard mutex"));
    let _pid_data_bg_container_display = pid_data_bg_container.clone();
    let pid_bg_data_container_pid_bg = pid_data_bg_container.clone();
    let pid_bg_data_container_main = pid_data_bg_container.clone();
    let pid_bg_data_container_usb = pid_data_bg_container;

    let interface = Interface::default();
    let interface_data_container =
        Arc::new(Mutex::new(interface).expect("Failed to create data guard mutex"));
    let _interface_data_container_display = interface_data_container.clone();
    let interface_data_container_main = interface_data_container.clone();
    let interface_data_container_usb = interface_data_container;

    let pump = PumpData::default();
    let pump_data_container =
        Arc::new(Mutex::new(pump).expect("Failed to create data guard mutex"));
    let _pump_data_container_display = pump_data_container.clone();
    let pump_data_container_main = pump_data_container.clone();
    let pump_data_container_usb = pump_data_container;

    let pump_command_queue = Arc::new(Queue::new(10).unwrap());
    let pump_command_queue_main = pump_command_queue.clone();
    let pump_command_queue_usb = pump_command_queue;

    let heater_1_command_queue = Arc::new(Queue::new(10).unwrap());
    let heater_1_command_queue_pid_1 = heater_1_command_queue.clone();
    let heater_1_command_queue_usb = heater_1_command_queue;

    let heater_2_command_queue = Arc::new(Queue::new(10).unwrap());
    let heater_2_command_queue_pid_2 = heater_2_command_queue.clone();
    let heater_2_command_queue_usb = heater_2_command_queue;

    let heater_bg_command_queue = Arc::new(Queue::new(10).unwrap());
    let heater_bg_command_queue_pid_bg = heater_bg_command_queue.clone();
    let heater_bg_command_queue_usb = heater_bg_command_queue;

    let valve_command_queue = Arc::new(Queue::new(10).unwrap());
    let valve_command_queue_main = valve_command_queue.clone();
    let valve_command_queue_usb = valve_command_queue;

    delay.delay(1000.millis());
    usb_println("boot up ok");
    fault_1_led.on();
    fault_2_led.on();
    delay.delay(100.millis());

    Task::new()
        .name("TEMPERATURE ADC TASK")
        .stack_size(1024)
        .priority(TaskPriority(4))
        .start(move || {
            let mut max31865_1 = MAX31865::new(spi_bus.acquire_spi(), cs_1, Wires::TwoWire);
            let mut max31865_2 = MAX31865::new(spi_bus.acquire_spi(), cs_2, Wires::TwoWire);
            let mut max31865_3 = MAX31865::new(spi_bus.acquire_spi(), cs_3, Wires::TwoWire);
            let mut max31865_4 = MAX31865::new(spi_bus.acquire_spi(), cs_4, Wires::TwoWire);
            let mut max31865_5 = MAX31865::new(spi_bus.acquire_spi(), cs_5, Wires::TwoWire);

            let max31865_1_state = max31865_1.init();
            let max31865_2_state = max31865_2.init();
            let max31865_3_state = max31865_3.init();
            let max31865_4_state = max31865_4.init();
            let max31865_5_state = max31865_5.init();

            loop {
                if check_shutdown() {
                    break;
                }

                let pressure = read_pressure();

                let t1 = if max31865_1_state.is_ok() {
                    max31865_1.get_temperature()
                } else {
                    None
                };
                let t2 = if max31865_2_state.is_ok() {
                    max31865_2.get_temperature()
                } else {
                    None
                };
                let t3 = if max31865_3_state.is_ok() {
                    max31865_3.get_temperature()
                } else {
                    None
                };
                let t4 = if max31865_4_state.is_ok() {
                    max31865_4.get_temperature()
                } else {
                    None
                };
                let t5 = if max31865_5_state.is_ok() {
                    max31865_5.get_temperature()
                } else {
                    None
                };

                if let Ok(mut measured_data) = measured_data_container_adc.lock(Duration::ms(5)) {
                    measured_data.t1 = t1;
                    measured_data.t2 = t2;
                    measured_data.t3 = t3;
                    measured_data.t4 = t4;
                    measured_data.t5 = t5;
                    measured_data.p = pressure;
                }
                CurrentTask::delay(Duration::ms(100));
            }
        })
        .unwrap();

    Task::new()
        .name("PID TASK")
        .stack_size(1024)
        .priority(TaskPriority(1))
        .start(move || {
            let mut heater_1_pid = PID::new();
            let mut heater_1_current_temperature = None;
            let mut heater_1_boiler_override = None;
            let mut heater_2_pid = PID::new();
            let mut heater_2_current_temperature = None;
            let mut heater_2_boiler_override = None;
            let mut heater_bg_pid = PID::new();
            let mut heater_bg_current_temperature = None;
            let mut heater_bg_boiler_override = None;

            let mut state = State::default();

            let mut mav_1 = Mav::new();
            let mut mav_2 = Mav::new();
            let mut mav_bg = Mav::new();

            let mut mav_1_counter = 0;
            let mut mav_2_counter = 0;
            let mut mav_bg_counter = 0;
            let mav_update_interval = 10;

            loop {
                if check_shutdown() {
                    heater_1_pwm.disable();
                    heater_1_pwm.set_duty(0);
                    heater_2_pwm.disable();
                    heater_2_pwm.set_duty(0);
                    heater_bg_pwm.disable(Channel::C3);
                    heater_bg_pwm.set_duty(Channel::C3, 0);
                    fault_2_led.off();
                    break;
                }

                if let Ok(state_temp) = state_container_pid.lock(Duration::ms(5)) {
                    state.pump_state = state_temp.pump_state.clone();
                    state.coffee_state = state_temp.coffee_state.clone();
                    state.valve_1_state = state_temp.valve_1_state.clone();
                    state.valve_2_state = state_temp.valve_2_state.clone();
                }

                mav_1_counter += 1;
                mav_2_counter += 1;
                mav_bg_counter += 1;

                if let Ok(cmd) = heater_1_command_queue_pid_1.receive(Duration::ms(5)) {
                    match cmd {
                        HeaterCommand::Temperature(temperature) => {
                            heater_1_pid.target = temperature
                        }
                        HeaterCommand::Heating(enable) => heater_1_pid.enabled = enable,
                        HeaterCommand::WindowSize(window_size) => {
                            heater_1_pid.window_size = window_size as u32;
                        }
                        HeaterCommand::PidP(kp) => heater_1_pid.kp = kp,
                        HeaterCommand::PidI(ki) => heater_1_pid.ki = ki,
                        HeaterCommand::PidD(kd) => heater_1_pid.kd = kd,
                        HeaterCommand::PidMaxVal(max_val) => heater_1_pid.max_val = max_val,
                        HeaterCommand::Boiler1(boiler_1) => heater_1_boiler_override = boiler_1,
                    }
                }

                if let Ok(mut pid_temp) = pid_1_data_container_pid_1.lock(Duration::ms(10)) {
                    // get values
                    heater_1_pid.enabled = pid_temp.enable;
                    heater_1_pid.kp = pid_temp.kp;
                    heater_1_pid.ki = pid_temp.ki;
                    heater_1_pid.kd = pid_temp.kd;
                    heater_1_pid.window_size = pid_temp.window_size;
                    heater_1_pid.max_val = pid_temp.max_val;
                    heater_1_pid.target = pid_temp.target;
                    // update current temperature for state machine
                    if let Ok(data) = measured_data_container_pid_1.lock(Duration::ms(5)) {
                        heater_1_current_temperature = data.t2;
                    }
                    pid_temp.current_temperature = heater_1_current_temperature;
                    // check if i has been reset
                    if pid_temp.reset_i {
                        heater_1_pid.i = 0.0;
                        pid_temp.reset_i = false;
                    }
                    // push values
                    pid_temp.p = heater_1_pid.p;
                    pid_temp.i = heater_1_pid.i;
                    pid_temp.d = heater_1_pid.d;
                    pid_temp.pid_val = heater_1_pid.val;
                    pid_temp.duty_cycle = heater_1_pid.duty_cycle;
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

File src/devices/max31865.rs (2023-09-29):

use embedded_hal::{
    blocking::spi::{Transfer, Write},
    digital::v2::OutputPin,
};

#[allow(unused)]
#[derive(PartialEq)]
pub enum Wires {
    TwoWire,
    ThreeWire,
    FourWire,
}

pub enum MAX31865Error<E> {
    RTDHighThreshold,
    RTDLowThreshold,
    RefInHigh,
    RefInLow,
    RTDInLow,
    OverUnderVoltage,
    SPIError(E),
    DefaultError,
}

pub struct MAX31865<SPI, CS> {
    spi: SPI,
    pub cs_pin: CS,
    pub wires: Wires,
}

impl<SPI, CS, E> MAX31865<SPI, CS>
where
    SPI: Transfer<u8, Error = E> + Write<u8, Error = E>,
    CS: OutputPin,
{
    pub fn new(spi: SPI, mut cs_pin: CS, wires: Wires) -> Self {
        cs_pin.set_high().ok();
        MAX31865 { spi, cs_pin, wires }
    }

    pub fn init(&mut self) -> Result<(), MAX31865Error<E>> {
        let data = match self.wires {
            Wires::TwoWire | Wires::FourWire => 0b11000000,
            Wires::ThreeWire => 0b11010000,
        };
        self.write(0x00, data)?;
        self.get_fault()
    }

    pub fn get_fault(&mut self) -> Result<(), MAX31865Error<E>> {
        let mut buffer = [0]; // first entry is register addr, next two will be data
        let f = self.read(0x07, &mut buffer).map(|_| buffer[0])?;
        if f & 0b10000000 == 0b10000000 {
            Err(MAX31865Error::RTDHighThreshold)
        } else if f & 0b01000000 == 0b01000000 {
            Err(MAX31865Error::RTDLowThreshold)
        } else if f & 0b00100000 == 0b00100000 {
            Err(MAX31865Error::RefInHigh)
        } else if f & 0b00010000 == 0b00010000 {
            Err(MAX31865Error::RefInLow)
        } else if f & 0b00001000 == 0b00001000 {
            Err(MAX31865Error::RTDInLow)
        } else if f & 0b000000100 == 0b000000100 {
            Err(MAX31865Error::OverUnderVoltage)
        } else {
            Ok(())
        }
    }

    pub fn get_raw(&mut self) -> Result<u16, MAX31865Error<E>> {
        let mut buffer = [0; 3]; // first entry is register addr, next two will be data
        match self.read(0x01, &mut buffer) {
            Ok(_) => {
                let data: u16 = (buffer[1] as u16) << 8 | (buffer[2] as u16);
                // if fault, then return Error
                if (data | 0b1) == 0b1 {
                    // let _ = self.init();
                    match self.get_fault() {
                        Ok(_) => Err(MAX31865Error::DefaultError),
                        Err(err) => Err(err),
                    }
                } else {
                    Ok(data >> 1)
                }
            }
            Err(err) => Err(err),
        }
    }

    pub fn get_resistance(&mut self) -> Option<f32> {
        const MAX31865_RREF: u16 = 400; // Reference resistor
        const MAX31865_FACTOR: u16 = 32768; // 2^15 used for data to resistance conversion
        if let Ok(raw_resistance) = self.get_raw() {
            Some((raw_resistance as f32 * MAX31865_RREF as f32) / MAX31865_FACTOR as f32)
            // offset for cable resistance
        } else {
            None
        }
    }

    pub fn get_temperature(&mut self) -> Option<f32> {
        const MAX31865_ALPHA: f32 = 0.003851; // PT-100 temperature coefficient
        self.get_resistance()
            .map(|resistance| ((resistance / 100.0) - 1.0) / MAX31865_ALPHA)
    }
    fn read(&mut self, register: u8, buffer: &mut [u8]) -> Result<(), MAX31865Error<E>> {
        buffer[0] = register;
        //usb_println(arrform!(64,"read cmd buffer {:?}", buffer).as_str());
        self.cs_pin.set_low().ok();
        match self.spi.transfer(buffer) {
            Ok(_) => {
                // usb_println(arrform!(64,"read answer {:?}",r).as_str());
            }
            Err(err) => {
                // usb_println(arrform!(64, "spi failed to read = {:?}", err).as_str());
                return Err(MAX31865Error::SPIError(err));
            }
        }
        self.cs_pin.set_high().ok();
        // usb_println(arrform!(64, "read payload = {:?}", buffer).as_str());
        Ok(())
    }

    fn write(&mut self, register: u8, payload: u8) -> Result<u8, MAX31865Error<E>> {
        let mut buffer: [u8; 2] = [register | 0x80, payload];
        self.cs_pin.set_low().ok();
        match self.spi.transfer(&mut buffer) {
            Ok(_) => {
                // usb_println(arrform!(64,"write answer {:?}",r).as_str());
            }
            Err(err) => {
                // usb_println(arrform!(64, "spi failed to write = {:?}", err).as_str());
                return Err(MAX31865Error::SPIError(err));
            }
        }
        self.cs_pin.set_high().ok();
        Ok(0)
    }
}

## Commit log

2023-01-06 freertos is not working with usb
    [main.rs, max31865.rs, usb.rs]
2023-01-15 screen is working (timer/tick not!)
2023-01-15 timer/tick count is working!
2023-01-17 implement PWM
2023-01-17 not sure if this file is needed...
    [stm32f4discovery.cfg]
2023-01-17 added hardware files of the electronics
    [AC_board.brd, AC_board.sch, main.brd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]
2023-01-19 implement mutex for temperature data to be shared between tasks
2023-01-20 implemented encoder with interrupt
2023-01-20 comment encoder interrupt
2023-01-21 command structure / housekeeping printing over USB
2023-01-22 implement bldc timer and LED task
2023-09-29 update max31865 temperature readout
2023-09-30 update temperature task
2023-10-01 update valve and heating tasks
2024-01-27 fix valve commanding and overrides
    [main.rs]
2024-01-27 also start heating via cmd
2024-01-27 fix valves
2024-01-27 read button
2024-01-27 pid to pd
2024-01-27 fix pump override
2024-01-27 fix bldc
2024-01-27 fix pwm
2024-01-27 pid to pi
2024-01-27 switch two valves
2024-01-27 fix pump ctrl
2024-02-18 adjust PID
2024-02-18 increase pre infuse power
2024-02-18 fix heating threshold
2024-02-18 fix heating condition
2024-02-18 implement second PID
2024-03-04 implement pressure sensor
2024-05-20 change pre-infuse power/timer
2025-03-11 implement other PID loops
2025-03-14 implement PID commands
2025-03-14 adjusted stack size and timer timeout
2025-03-16 debug Pressure
2025-05-18 fix pressure adc

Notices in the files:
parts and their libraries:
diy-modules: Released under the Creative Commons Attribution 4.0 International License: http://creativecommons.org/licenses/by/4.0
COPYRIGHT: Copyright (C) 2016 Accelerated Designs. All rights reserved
